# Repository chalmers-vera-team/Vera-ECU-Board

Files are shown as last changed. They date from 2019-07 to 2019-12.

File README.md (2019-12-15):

# Vera-ECU-Board
A PCB to break out connections to a MicroSquirt Engine Control Unit. Meant to be implemented for the Vera car of Chalmers Vera Team.
PCBWay sponsored the PCB and you can read about it [here!](http://chalmersverateam.se/wp-content/uploads/2019/12/PCBWAY_2019.pdf) 






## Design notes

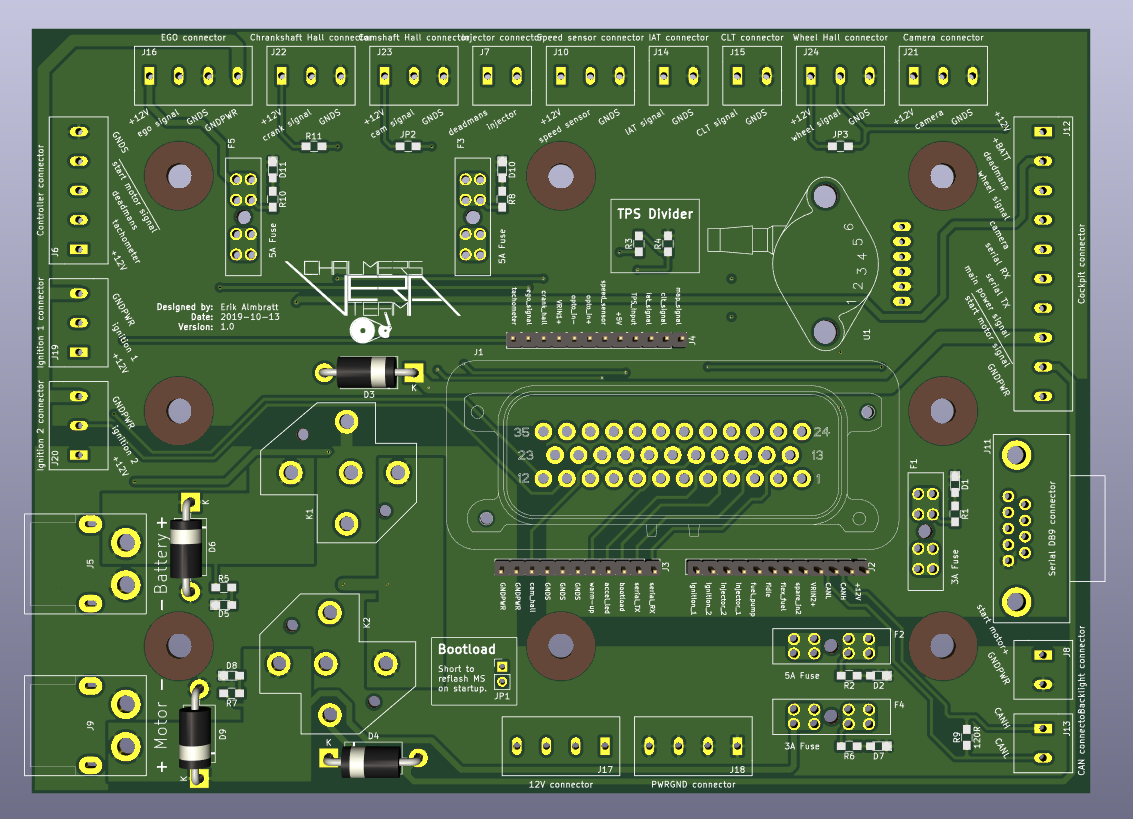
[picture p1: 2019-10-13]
ecu-board/ecu-board-model.png

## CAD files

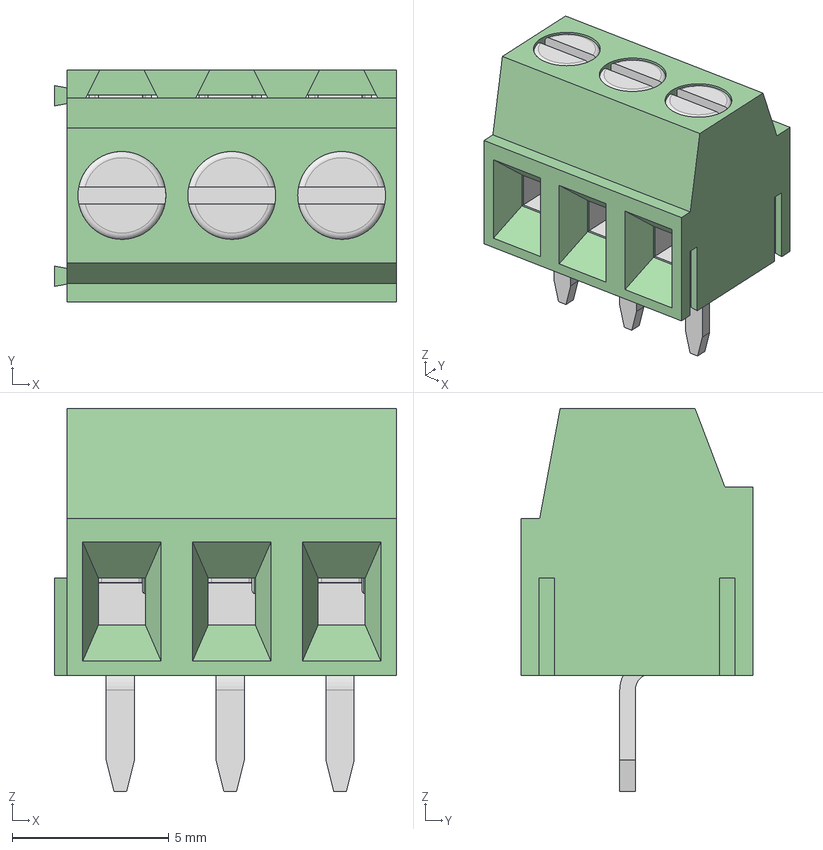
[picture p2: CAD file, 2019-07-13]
ecu-board/ecu-board-3d/wurth_2141_03x3.5mm.stp
10.9 x 7.40 x 12.2 mm
6912141100xx_CAGE x 3
6912141100xx_PIN x 3
6912141100xx_VIS x 3

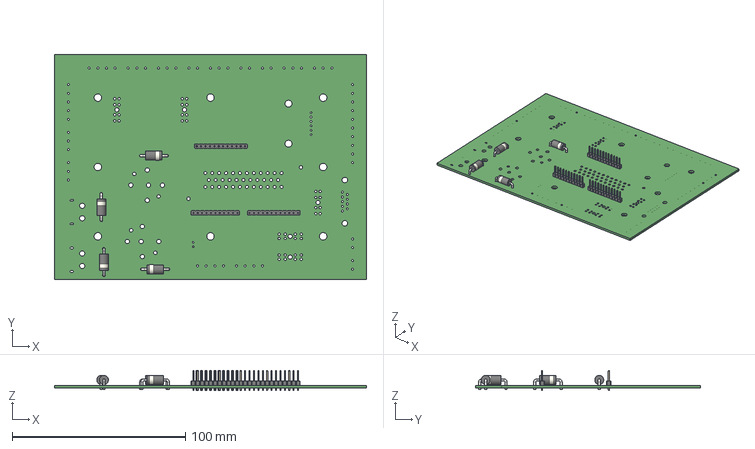
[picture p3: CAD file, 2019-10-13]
ecu-board/ecu-board.step
180.0 x 130.0 x 11.5 mm

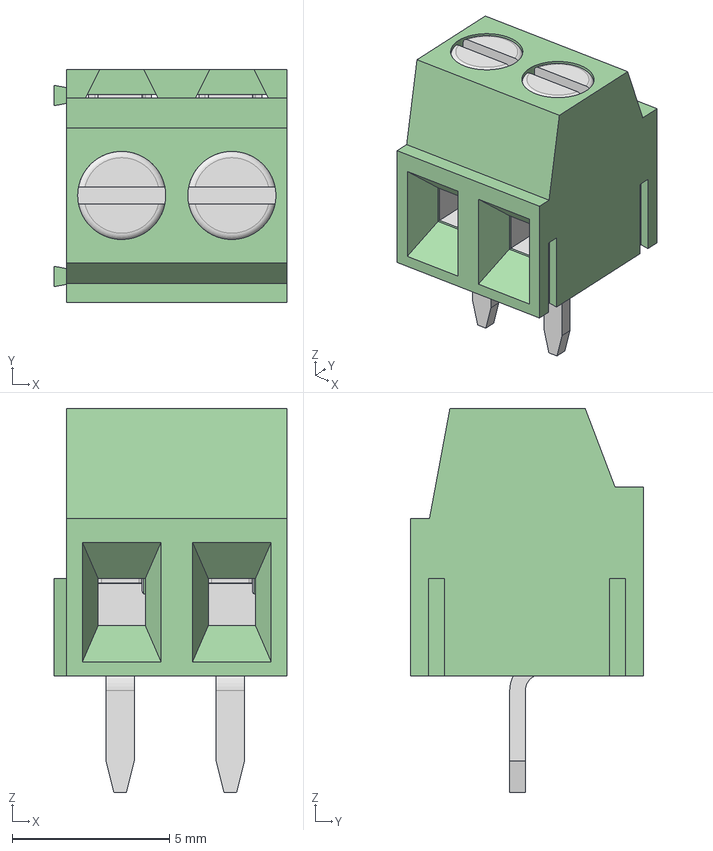
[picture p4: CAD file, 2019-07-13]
ecu-board/ecu-board-3d/wurth_2141_02x3.5mm.stp
7.40 x 7.40 x 12.2 mm
6912141100xx_CAGE x 2
6912141100xx_PIN x 2
6912141100xx_VIS x 2

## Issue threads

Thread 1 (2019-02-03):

Update crankshaft sensor model

tsuum, 2019-02-03:
Missing

tsuum, 2019-02-10:
cykn8-02cl0

Closed 2019-02-24.

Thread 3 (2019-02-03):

Make sure serial connector is correct in schematic

almbr, 2019-02-03:

Closed 2019-09-29.

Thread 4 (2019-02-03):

Verify 30A Main power fuse dimension

almbr, 2019-02-03:

tsuum, 2019-03-26:
Change to 50 A fuse. Need to use larger fuse socket.

almbr, 2019-05-16:
It's not reasonable to source a PCB-mount fuse socket of such high current rating. A in-line cable mount socket is more fit.

Closed 2019-05-16.

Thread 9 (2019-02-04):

Verify hall sensor connection

almbr, 2019-02-04:

tsuum, 2019-03-26:
Verify crankshaft sensor pull up.

almbr, 2019-05-15:
Crankshaft sensor does require pull up.

Verify that VR2IN- (cam) and VRIN1- (crank) are in use.

Closed 2019-07-04.

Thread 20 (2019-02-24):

Adapt to HMI connector board

tsuum, 2019-02-24:
- [x] Add wheel hall sensor.
- [x] Add wheel hall sensor to HMI out.
      12V/5V? And Signal?
- [x] Merge button input and HMI connector
- [x] Add Injector input button.
- [x] Add camera connector. (RCA, GNDS)
- [x] Add Serial rx, and tx

tsuum, 2019-02-24:
Need to hear with Oskar that everything is correct.

Closed 2019-03-26.

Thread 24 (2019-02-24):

Specify missing components

almbr, 2019-02-24:
- [ ] Large connectors
- [ ] New connectors
- [ ] Passives

Closed 2019-10-12.

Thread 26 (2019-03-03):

Double check Intakte air temperature circuit

almbr, 2019-03-03:
Seems like there might be a pull up in the wiring or something.

almbr, 2019-07-04:
http://www.msextra.com/doc/pdf/html/MS2V30_Hardware-3.4.pdf/MS2V30_Hardware-3.4.html

Closed 2019-07-04.

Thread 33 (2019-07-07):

Create terminal block footprint

almbr, 2019-07-07:

almbr, 2019-07-07:
**Terminals:**
https://www.phoenixcontact.com/gb/products/1791826
https://se.rs-online.com/web/p/terminal-block-accessories/1017015/?sra=pmpn

**End terminals:**
https://www.phoenixcontact.com/gb/products/1791868
https://se.rs-online.com/web/p/pcb-terminal-blocks/1017037/?sra=pmpn

Closed 2019-07-13.

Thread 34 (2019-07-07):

Create power connector footprint

almbr, 2019-07-07:

almbr, 2019-07-07:
https://se.rs-online.com/web/p/compact-power-connectors/1805375/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

Closed 2019-08-06.

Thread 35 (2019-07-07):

Implement reverse polarity protection

almbr, 2019-07-07:

almbr, 2019-07-08:
https://se.rs-online.com/web/p/mosfets/9064343/

Closed 2019-07-08.

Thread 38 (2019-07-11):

Verify reverse polarity protection circuit

almbr, 2019-07-11:

almbr, 2019-07-13:
Tested. Works well.

Closed 2019-07-13.

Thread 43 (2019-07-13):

Choose relays

almbr, 2019-07-13:
Maybe good source? https://www.12voltplanet.co.uk/relay-guide.html

almbr, 2019-07-13:
Make sure to be compliant with DIN 72552. Orient coil poles correctly to allow for integrated diode. Use ISO mini relays.

almbr, 2019-08-16:
Make relay symbol

Closed 2019-08-17.

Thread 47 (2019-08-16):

Correct Ampseal footprint name.

almbr, 2019-08-16:

almbr, 2019-08-17:
Not related to project. Take care of later.

Closed 2019-08-17.

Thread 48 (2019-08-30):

Redesign mosfet footprint

almbr, 2019-08-30:
For temp. Via in pad. Larger coolant pad.

Maybe heatsink?

Closed 2019-09-29.

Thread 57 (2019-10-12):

Double check no relay power traces are broken

almbr, 2019-10-12:

Closed 2019-10-12.

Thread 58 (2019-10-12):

Order

almbr, 2019-10-12:
- [x] Fuse holders
- [ ] Cable
- [x] Terminal blocks
- [x] Small cable ferrules
- [x] PCB spacers

Closed 2019-10-23.

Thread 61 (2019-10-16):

Larger clearance on mounting holes

almbr, 2019-10-16:
The tolerance between the solder mask and copper clearance is rather small. If the solder mask is missaligned there is a risk of a short circuit between the 12V and GND copper pours.

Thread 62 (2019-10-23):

Shorten Connector symbol values

almbr, 2019-10-23:
Footprint values are rewritten on update netlist. Therefore symbol values needs to be shortened. I.e. "EGO Connector" to "EGO".

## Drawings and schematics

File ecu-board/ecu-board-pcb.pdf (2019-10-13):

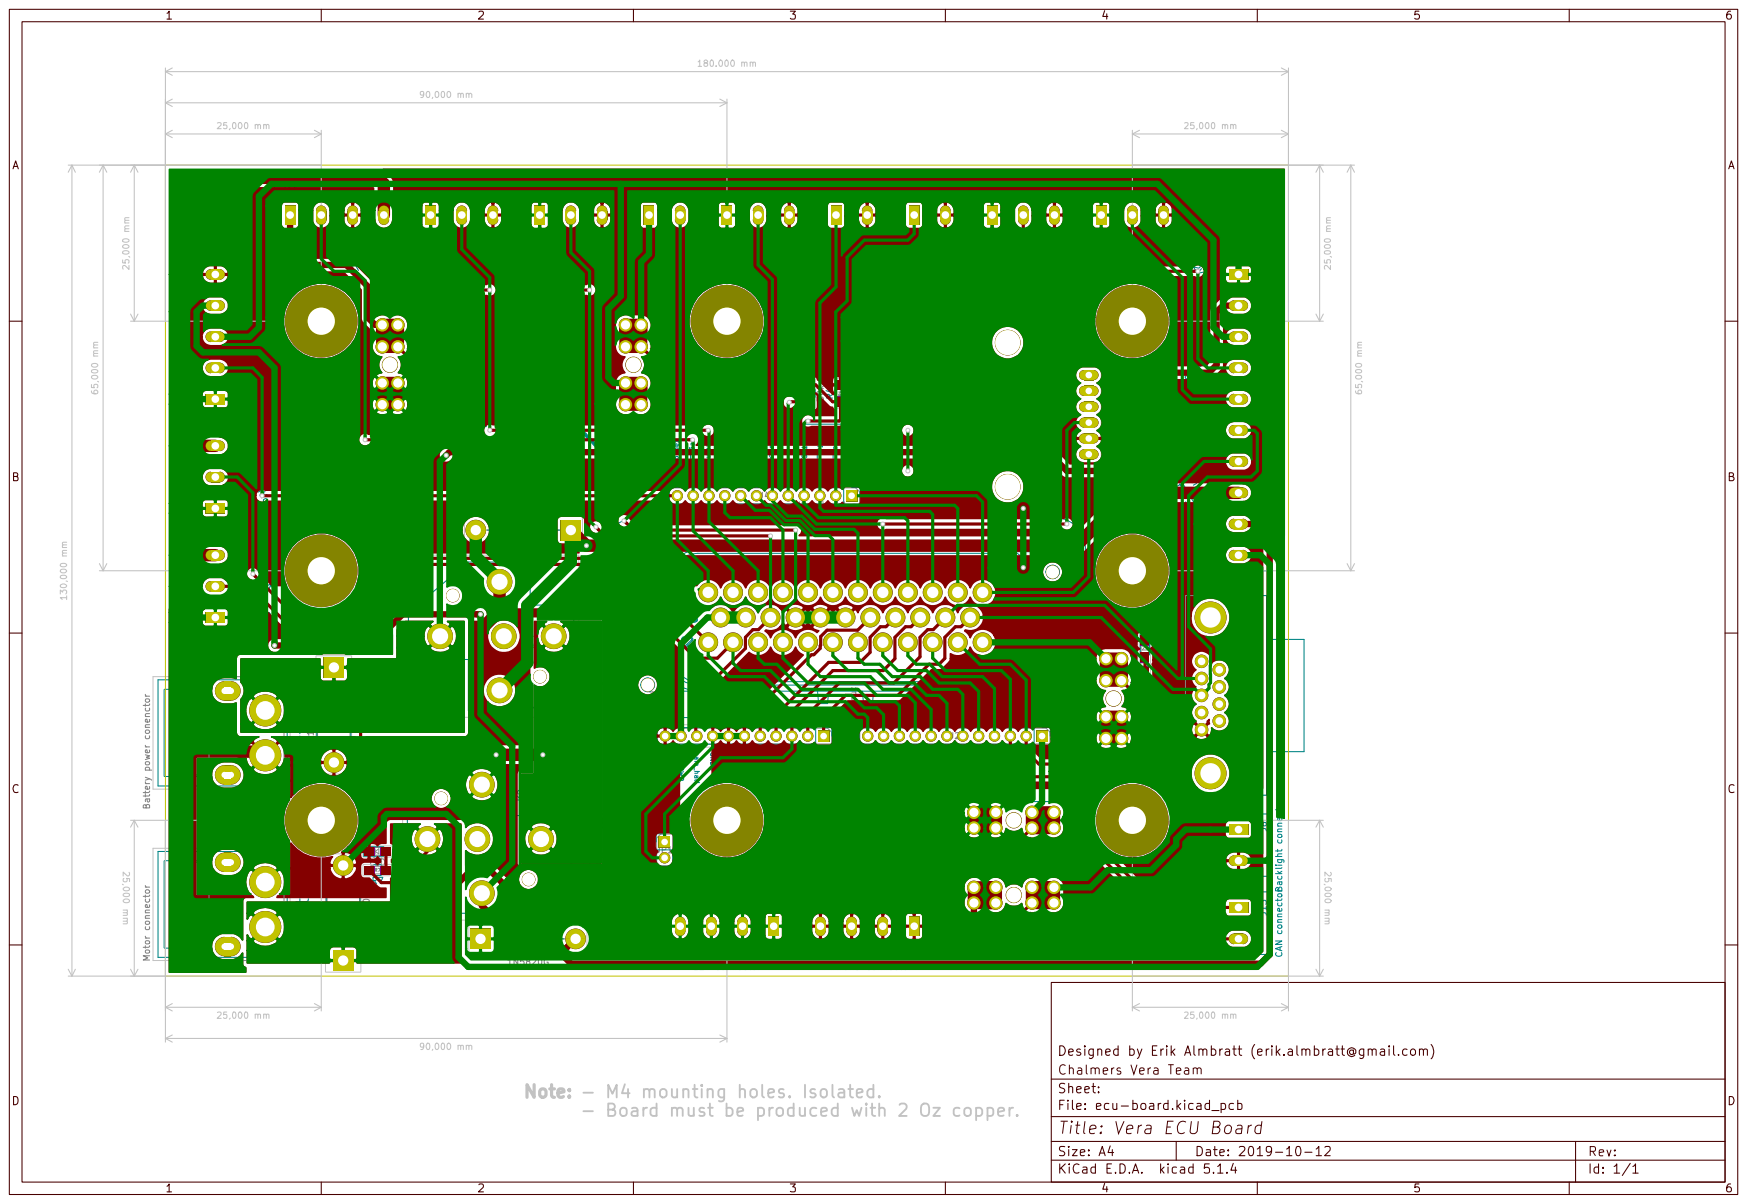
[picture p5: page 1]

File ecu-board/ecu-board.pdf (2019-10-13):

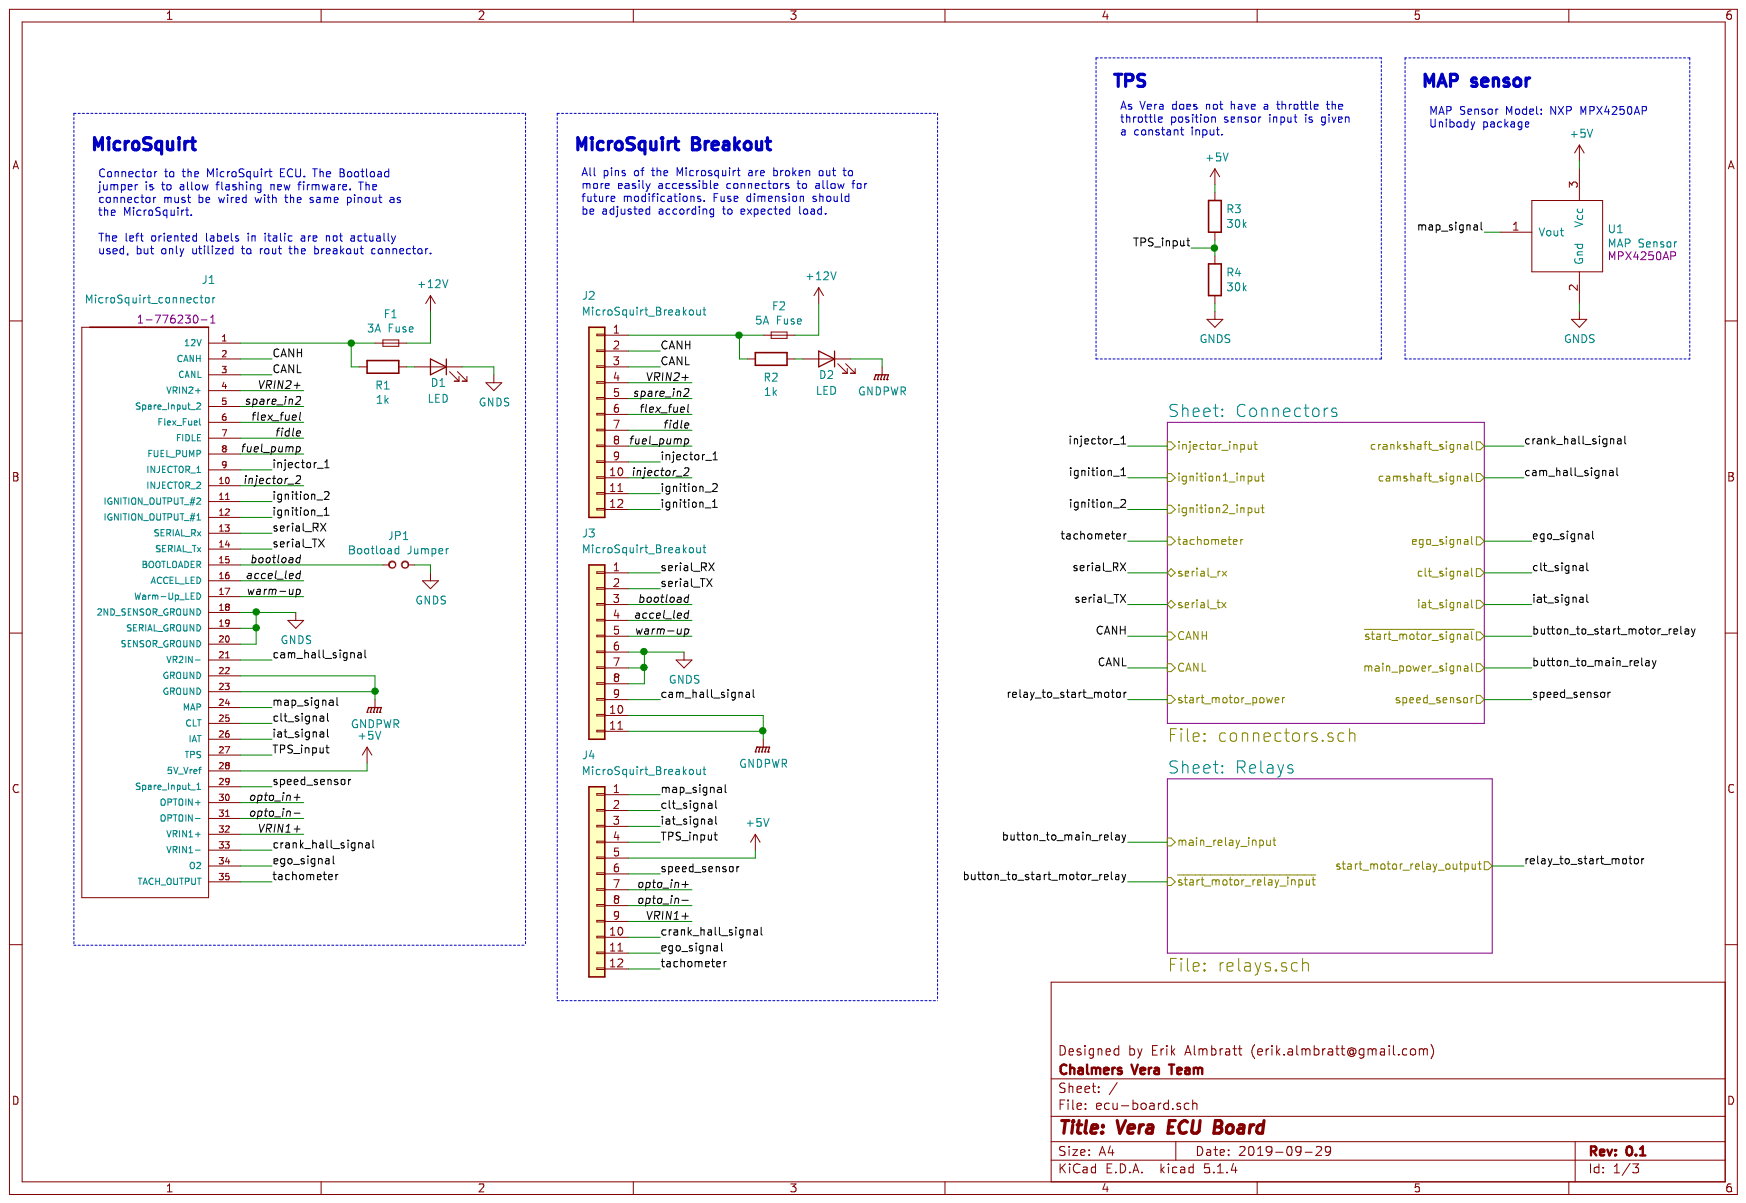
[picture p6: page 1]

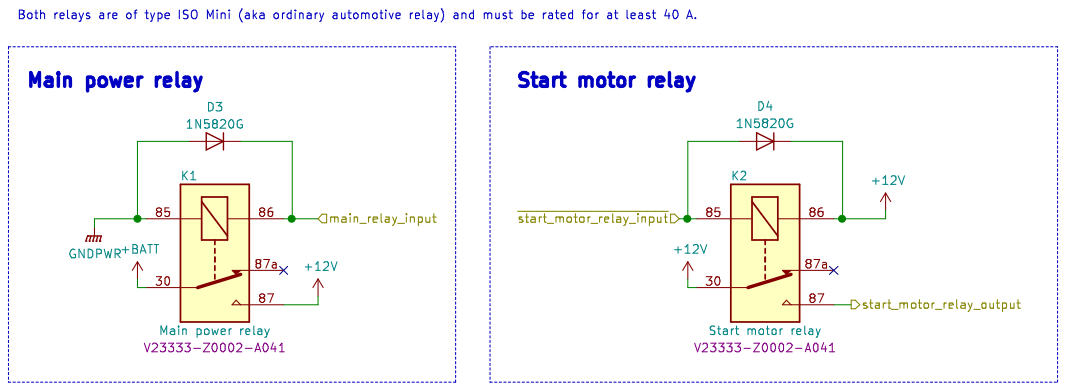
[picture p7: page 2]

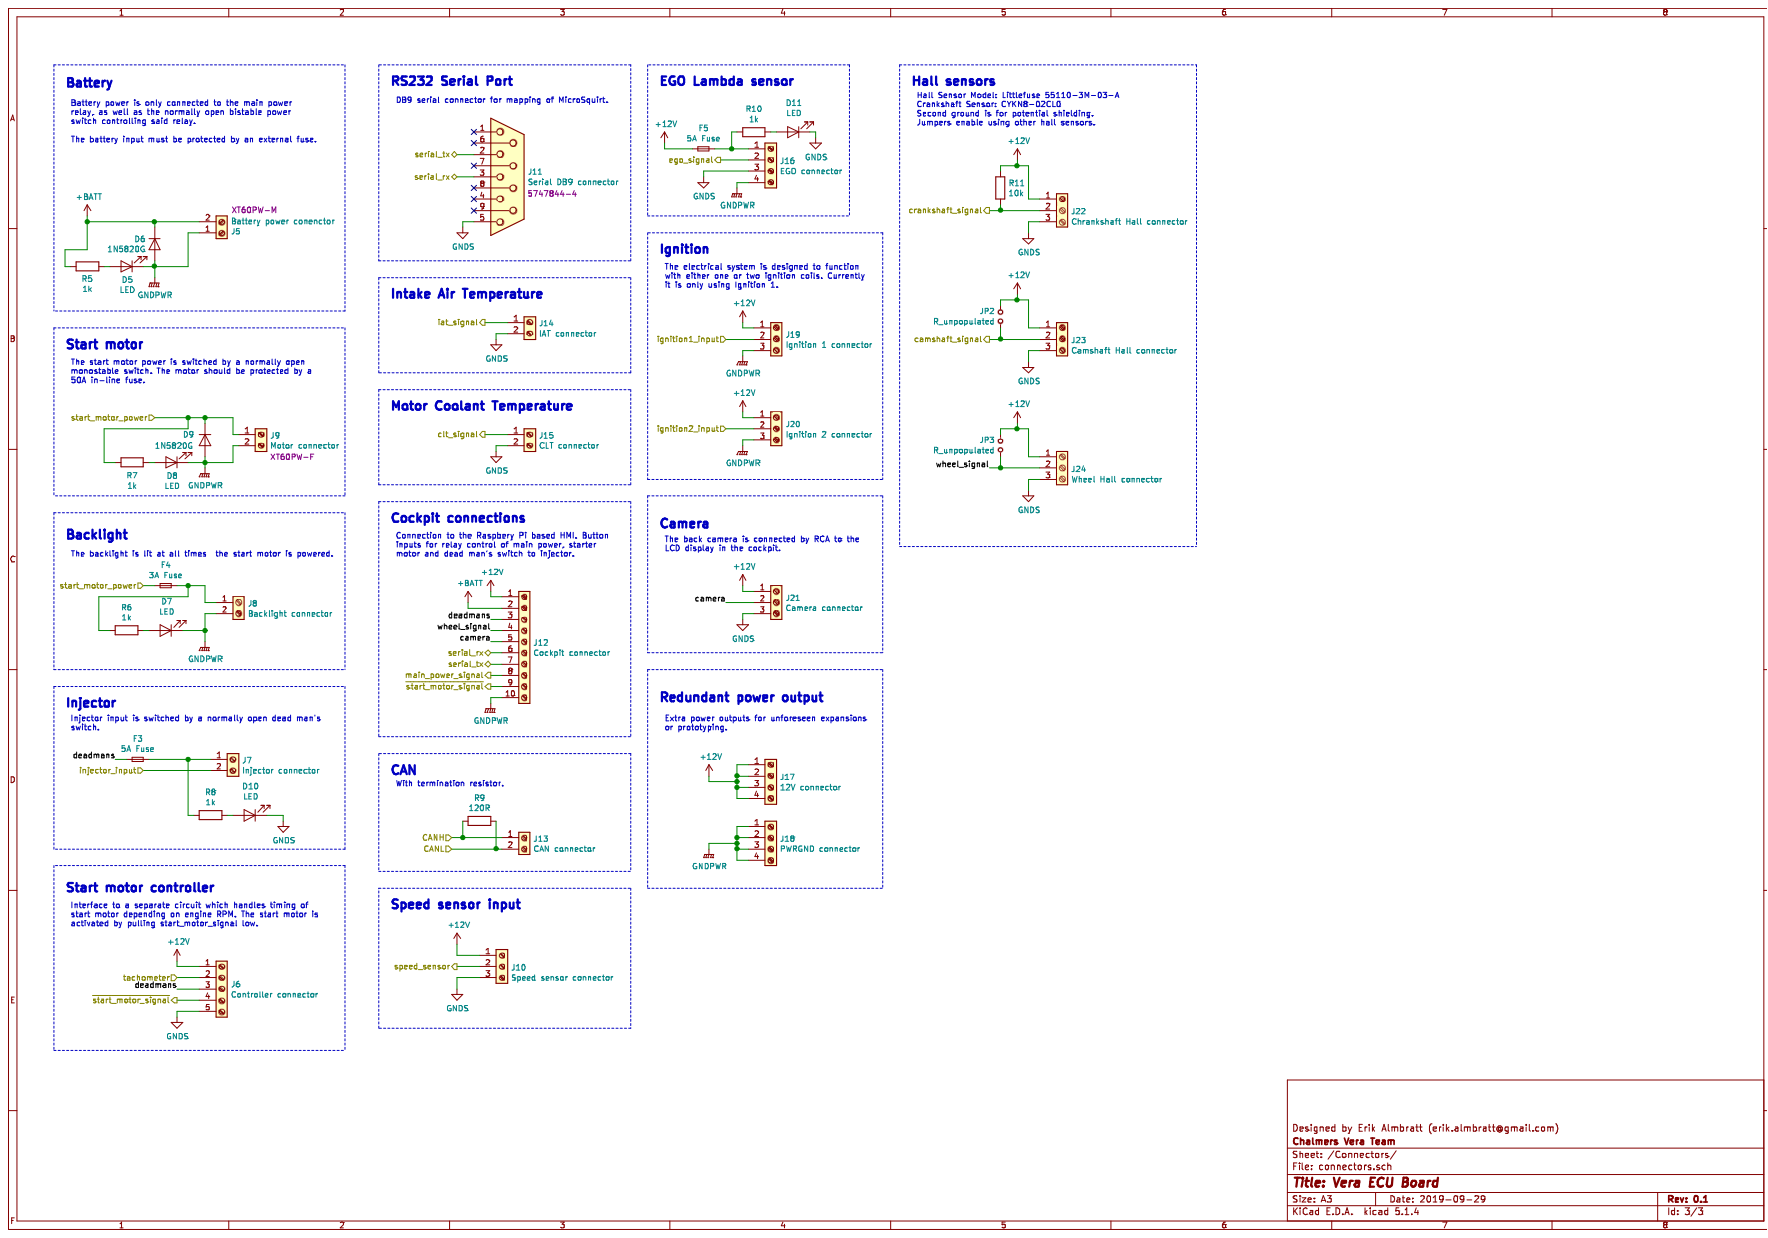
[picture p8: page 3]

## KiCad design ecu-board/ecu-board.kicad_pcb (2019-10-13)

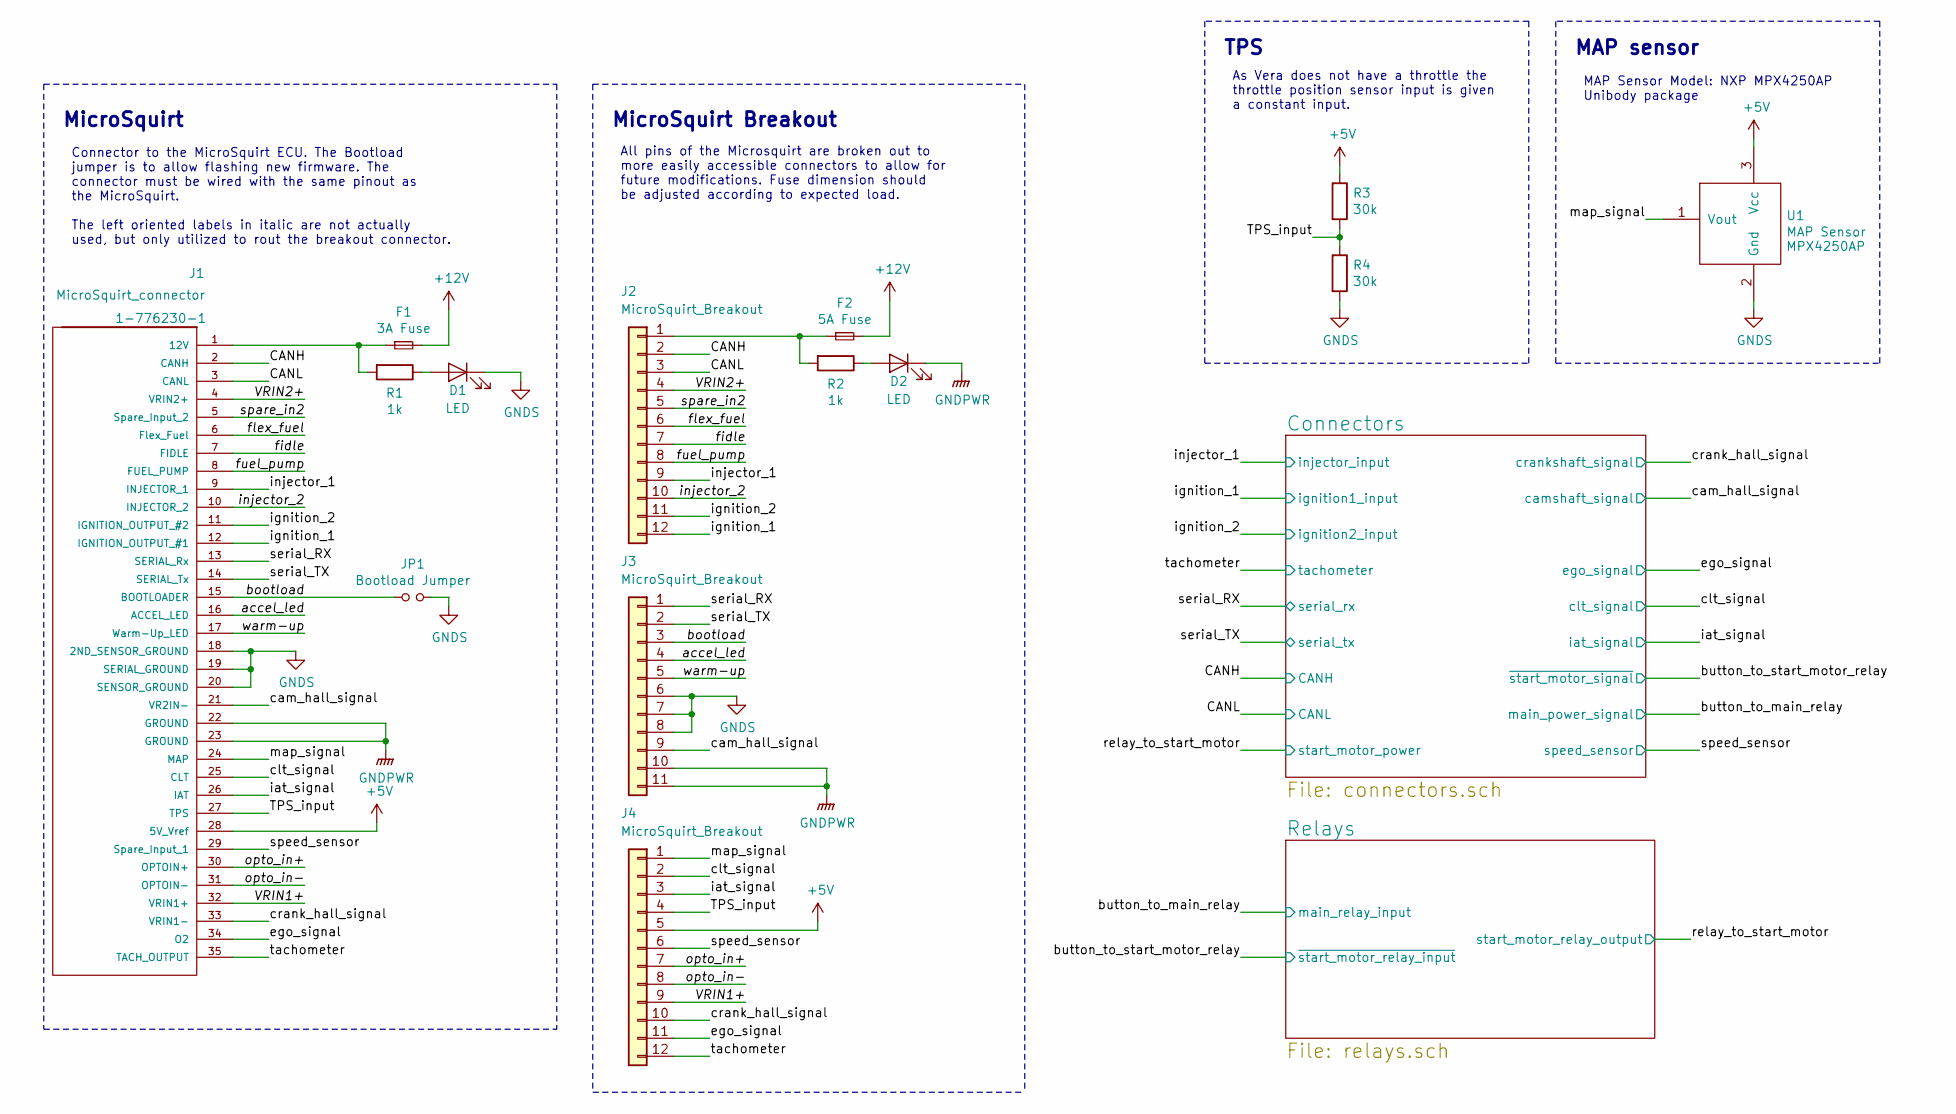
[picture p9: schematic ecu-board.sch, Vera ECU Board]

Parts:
D1, D2: LED; LED_0805_HandSoldering; Part no. 0805
F1: 3A Fuse; Fuseholder_ATO_Blade_Littelfuse_Pudenz_4_Pin; Part no. 178.4265.0002
F2: 5A Fuse; Fuseholder_ATO_Blade_Littelfuse_Pudenz_4_Pin; Part no. 178.4265.0002
J1: MicroSquirt_connector; TE_1-776230-1_35POS_P4.0mm_Vertical; Part no. 1-776230-1
J2, J4: MicroSquirt_Breakout; PinHeader_1x12_P2.54mm_Vertical; Part no. 2.54mm Pin Header
J3: MicroSquirt_Breakout; PinHeader_1x11_P2.54mm_Vertical; Part no. 2.54mm Pin Header
JP1: Bootload Jumper; Pin_Header_Straight_1x02_Pitch2.54mm; Part no. 2.54mm Pin Header
R1, R2: 1k; R_0805_HandSoldering; Part no. 0805
R3, R4: 30k; R_0805_HandSoldering; Part no. 0805
U1: MAP Sensor; SOT1852-1; Part no. MPX4250AP

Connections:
+5V: J1.28 (5V_Vref), J4.5, R3.1, U1.3 (Vcc)
+12V: F1.2, F2.2; also elsewhere on the board
/CANH: J1.2 (CANH), J2.2; also elsewhere on the board
/CANL: J1.3 (CANL), J2.3; also elsewhere on the board
/TPS_input: J1.27 (TPS), J4.4, R3.2, R4.1
/VRIN1+: J1.32 (VRIN1+), J4.9
/VRIN2+: J1.4 (VRIN2+), J2.4
/accel_led: J1.16 (ACCEL_LED), J3.4
/bootload: J1.15 (BOOTLOADER), J3.3, JP1.1
/cam_hall_signal: J1.21 (VR2IN-), J3.9; also elsewhere on the board
/clt_signal: J1.25 (CLT), J4.2; also elsewhere on the board
/crank_hall_signal: J1.33 (VRIN1-), J4.10; also elsewhere on the board
/ego_signal: J1.34 (O2), J4.11; also elsewhere on the board
/fidle: J1.7 (FIDLE), J2.7
/flex_fuel: J1.6 (Flex_Fuel), J2.6
/fuel_pump: J1.8 (FUEL_PUMP), J2.8
/iat_signal: J1.26 (IAT), J4.3; also elsewhere on the board
/ignition_1: J1.12 (IGNITION_OUTPUT_#1), J2.12; also elsewhere on the board
/ignition_2: J1.11 (IGNITION_OUTPUT_#2), J2.11; also elsewhere on the board
/injector_1: J1.9 (INJECTOR_1), J2.9; also elsewhere on the board
/injector_2: J1.10 (INJECTOR_2), J2.10
/map_signal: J1.24 (MAP), J4.1, U1.1 (Vout)
/opto_in+: J1.30 (OPTOIN+), J4.7
/opto_in-: J1.31 (OPTOIN-), J4.8
/serial_RX: J1.13 (SERIAL_Rx), J3.1; also elsewhere on the board
/serial_TX: J1.14 (SERIAL_Tx), J3.2; also elsewhere on the board
/spare_in2: J1.5 (Spare_Input_2), J2.5
/speed_sensor: J1.29 (Spare_Input_1), J4.6; also elsewhere on the board
/tachometer: J1.35 (TACH_OUTPUT), J4.12; also elsewhere on the board
/warm-up: J1.17 (Warm-Up_LED), J3.5
GNDPWR: D2.1 (K), J1.22 (GROUND), J1.23 (GROUND), J3.10, J3.11; also elsewhere on the board
GNDS: D1.1 (K), J1.18 (2ND_SENSOR_GROUND), J1.19 (SERIAL_GROUND), J1.20 (SENSOR_GROUND), J3.6, J3.7, J3.8, JP1.2, R4.2, U1.2 (Gnd); also elsewhere on the board
unnamed: D1.2 (A), R1.1
unnamed: D2.2 (A), R2.1
unnamed: F1.1, J1.1 (12V), R1.2
unnamed: F2.1, J2.1, R2.2

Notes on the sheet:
MicroSquirt
Connector to the MicroSquirt ECU. The Bootload jumper is to allow flashing new firmware. The connector must be wired with the same pinout as the MicroSquirt. The left oriented labels in italic are not actually used, but only utilized to rout the breakout connector.
MAP sensor
MAP Sensor Model: NXP MPX4250AP Unibody package
TPS
As Vera does not have a throttle the throttle position sensor input is given a constant input.
MicroSquirt Breakout
All pins of the Microsquirt are broken out to more easily accessible connectors to allow for future modifications. Fuse dimension should be adjusted according to expected load.

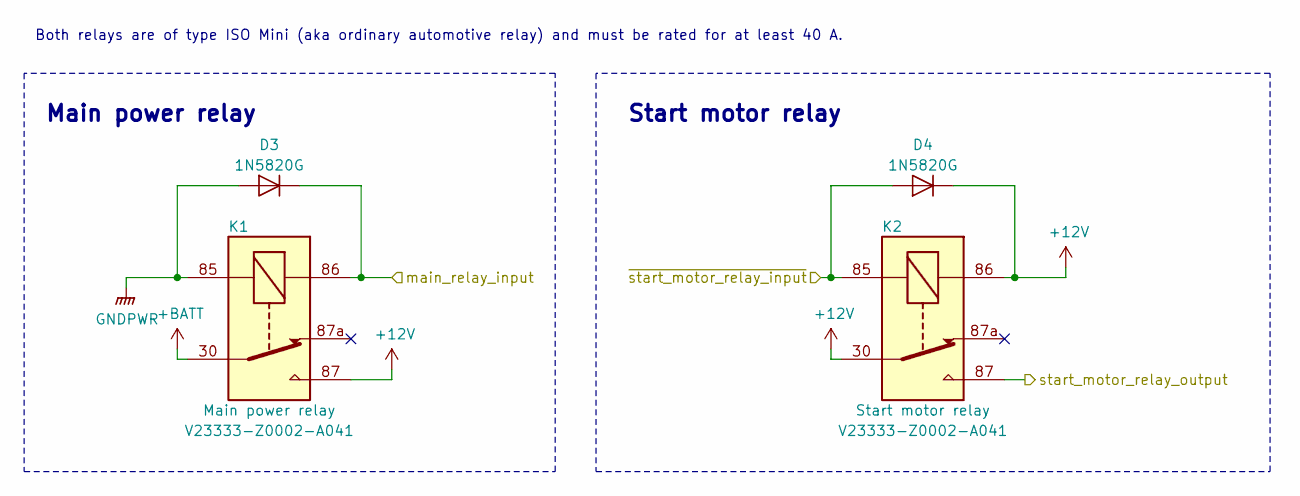
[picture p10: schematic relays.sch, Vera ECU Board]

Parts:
D3, D4: 1N5820G; D_DO-201AD_P15.24mm_Horizontal; Part no. 1N5820G
K1: Main power relay; TE_2-1904045-4; Part no. V23333-Z0002-A041
K2: Start motor relay; TE_2-1904045-4; Part no. V23333-Z0002-A041

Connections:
+12V: D4.1 (K), K1.87, K2.30, K2.86; also elsewhere on the board
+BATT: K1.30; also elsewhere on the board
/button_to_main_relay: D3.1 (K), K1.86; also elsewhere on the board
/button_to_start_motor_relay: D4.2 (A), K2.85; also elsewhere on the board
/relay_to_start_motor: K2.87; also elsewhere on the board
GNDPWR: D3.2 (A), K1.85; also elsewhere on the board

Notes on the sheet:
Main power relay
Start motor relay
Both relays are of type ISO Mini (aka ordinary automotive relay) and must be rated for at least 40 A.

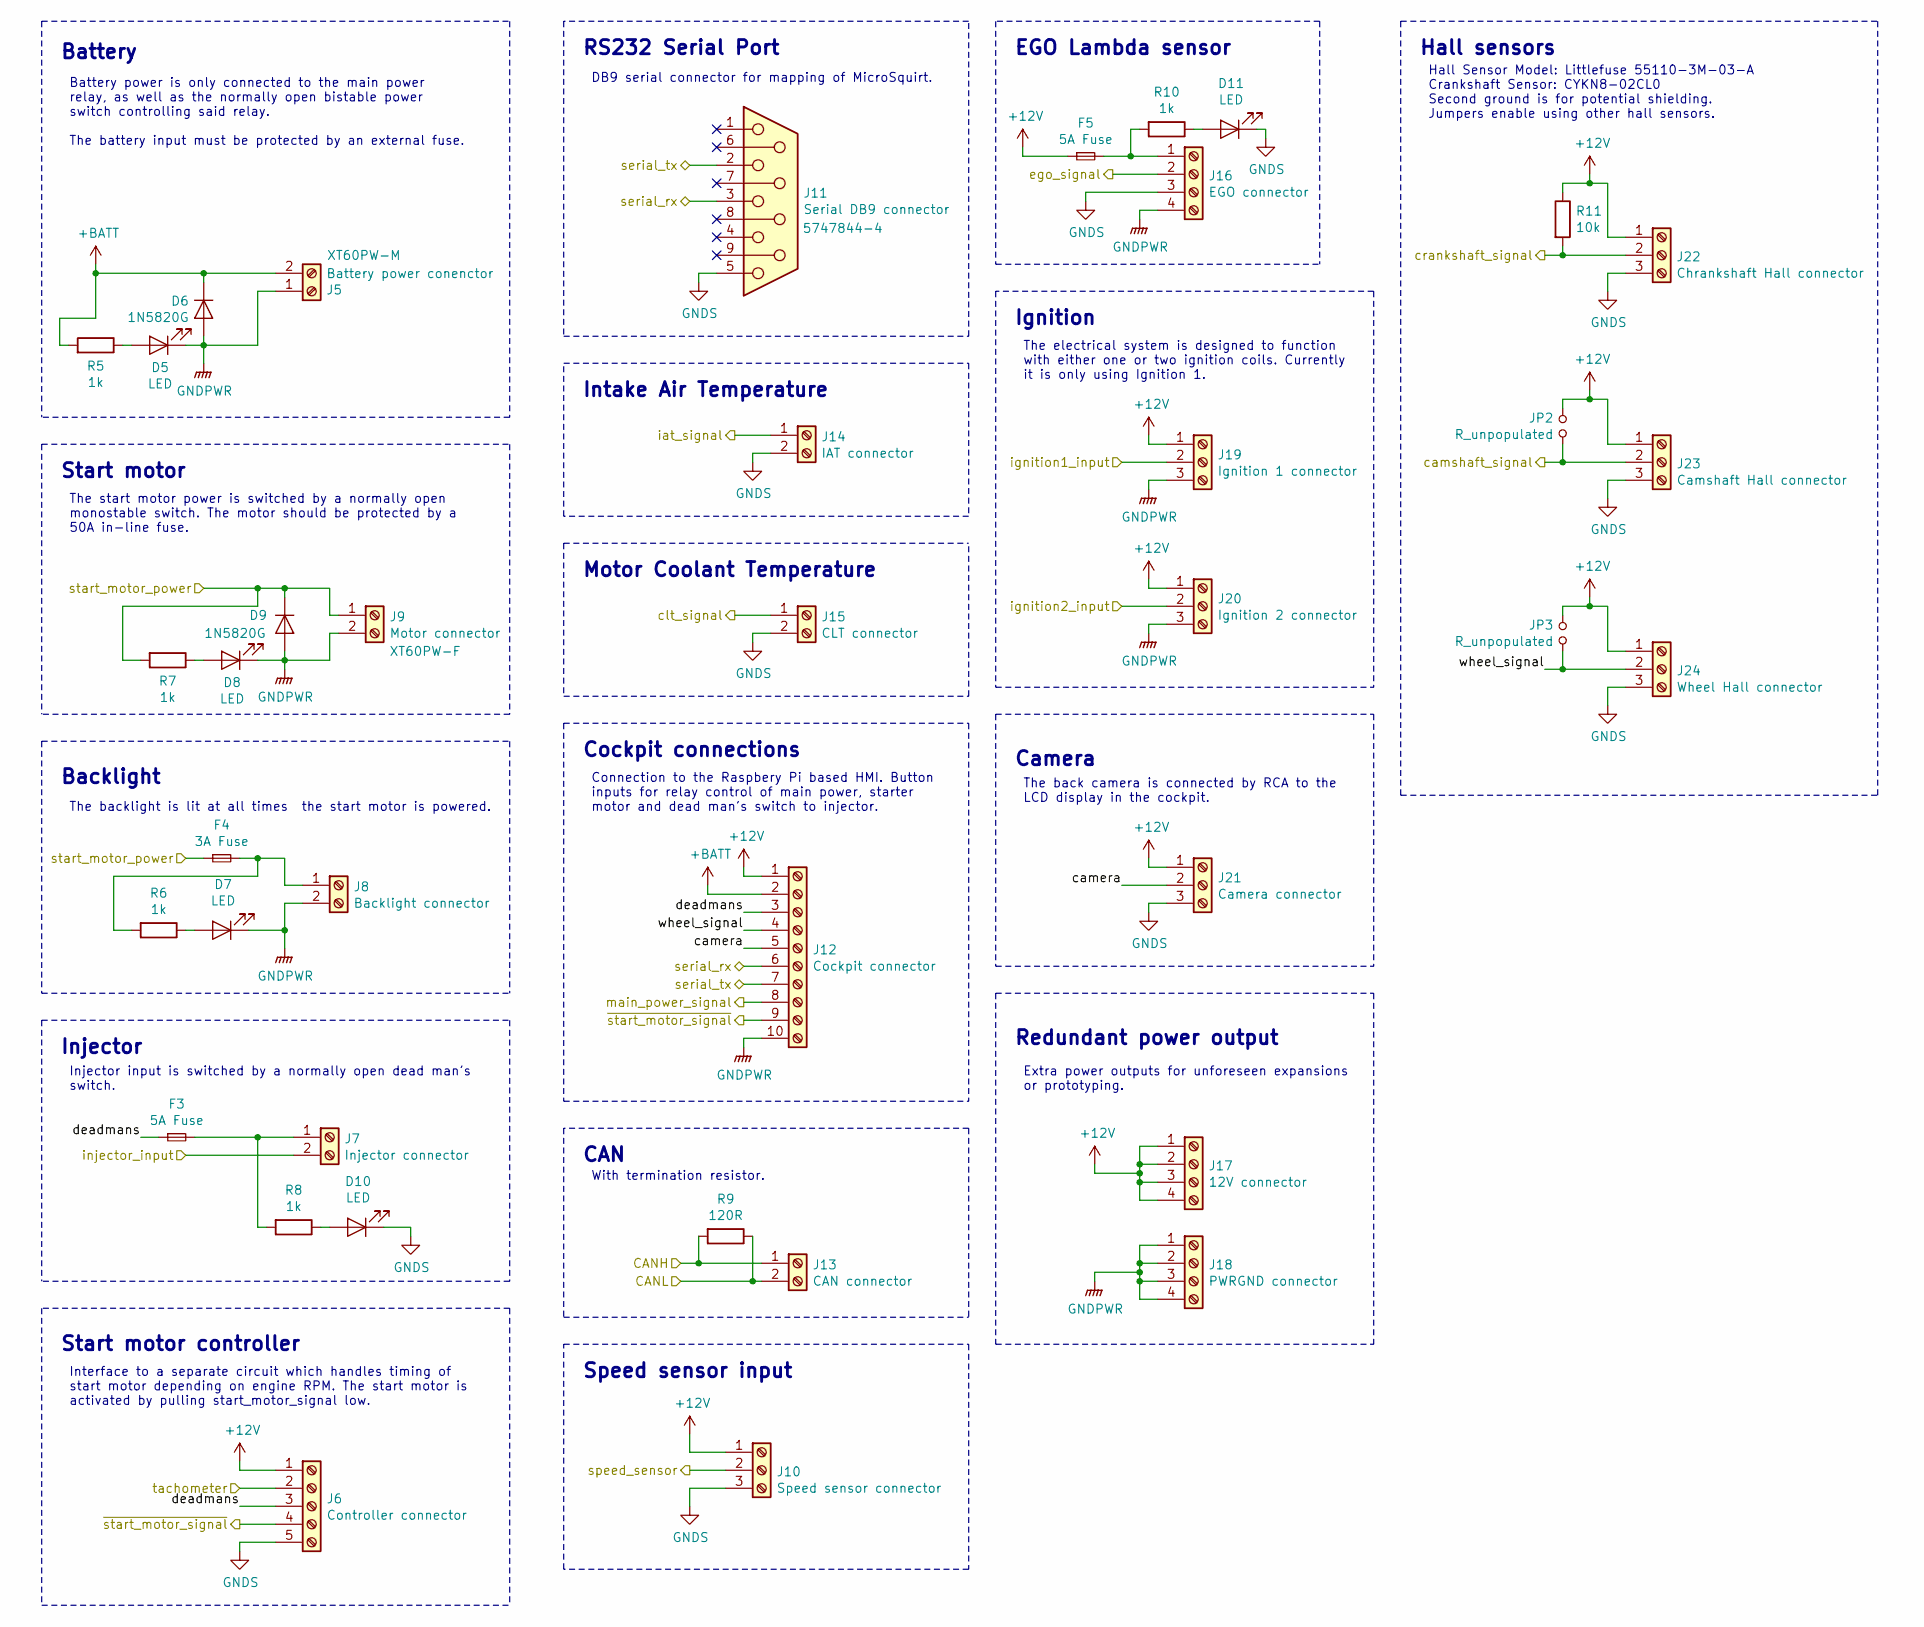
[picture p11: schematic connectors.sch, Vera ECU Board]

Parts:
D5, D7, D8, D10, D11: LED; LED_0805_HandSoldering; Part no. 0805
D6, D9: 1N5820G; D_DO-201AD_P15.24mm_Horizontal; Part no. 1N5820G
F3, F5: 5A Fuse; Fuseholder_ATO_Blade_Littelfuse_Pudenz_4_Pin; Part no. 178.4265.0002
F4: 3A Fuse; Fuseholder_ATO_Blade_Littelfuse_Pudenz_4_Pin; Part no. 178.4265.0002
J5: Battery power conenctor; AMASS_XT60PW; Part no. XT60PW-M
J6: Controller connector; Terminal_Block_5x5.00mm; Part no. 897-0812
J7: Injector connector; Terminal_Block_2x5.00mm; Part no. 897-0803
J8: Backlight connector; Terminal_Block_2x5.00mm; Part no. 897-0803
J9: Motor connector; AMASS_XT60PW; Part no. XT60PW-F
J10: Speed sensor connector; Terminal_Block_3x5.00mm; Part no. 897-0812
J11: Serial DB9 connector; TE_5747844-4; Part no. 5747844-4
J12: Cockpit connector; Terminal_Block_10x5.00mm; Part no. 897-0803
J13: CAN connector; Terminal_Block_2x5.00mm; Part no. 897-0803
J14: IAT connector; Terminal_Block_2x5.00mm; Part no. 897-0803
J15: CLT connector; Terminal_Block_2x5.00mm; Part no. 897-0803
J16: EGO connector; Terminal_Block_4x5.00mm; Part no. 897-0803
J17: 12V connector; Terminal_Block_4x5.00mm; Part no. 897-0803
J18: PWRGND connector; Terminal_Block_4x5.00mm; Part no. 897-0803
J19: Ignition 1 connector; Terminal_Block_3x5.00mm; Part no. 897-0812
J20: Ignition 2 connector; Terminal_Block_3x5.00mm; Part no. 897-0812
J21: Camera connector; Terminal_Block_3x5.00mm; Part no. 897-0812
J22: Chrankshaft Hall connector; Terminal_Block_3x5.00mm; Part no. 897-0812
J23: Camshaft Hall connector; Terminal_Block_3x5.00mm; Part no. 897-0812
J24: Wheel Hall connector; Terminal_Block_3x5.00mm; Part no. 897-0812
JP2, JP3: R_unpopulated; R_0805_HandSoldering; Part no. 0805
R5, R6, R7, R8, R10: 1k; R_0805_HandSoldering; Part no. 0805
R9: 120R; R_0805_HandSoldering; Part no. 0805
R11: 10k; R_0805_HandSoldering; Part no. 0805

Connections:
+12V: F5.1, J6.1, J10.1, J12.1, J17.1, J17.2, J17.3, J17.4, J19.1, J20.1, J21.1, J22.1, J23.1, J24.1, JP2.2, JP3.2, R11.1; also elsewhere on the board
+BATT: D6.1 (K), J5.2, J12.2, R5.2; also elsewhere on the board
/CANH: J13.1, R9.2; also elsewhere on the board
/CANL: J13.2, R9.1; also elsewhere on the board
/Connectors/camera: J12.5, J21.2
/Connectors/deadmans: F3.1, J6.3, J12.3
/Connectors/wheel_signal: J12.4, J24.2, JP3.1
/button_to_main_relay: J12.8; also elsewhere on the board
/button_to_start_motor_relay: J6.4, J12.9; also elsewhere on the board
/cam_hall_signal: J23.2, JP2.1; also elsewhere on the board
/clt_signal: J15.1; also elsewhere on the board
/crank_hall_signal: J22.2, R11.2; also elsewhere on the board
/ego_signal: J16.2; also elsewhere on the board
/iat_signal: J14.1; also elsewhere on the board
/ignition_1: J19.2; also elsewhere on the board
/ignition_2: J20.2; also elsewhere on the board
/injector_1: J7.2; also elsewhere on the board
/relay_to_start_motor: D9.1 (K), F4.1, J9.1, R7.2; also elsewhere on the board
/serial_RX: J11.3, J12.6; also elsewhere on the board
/serial_TX: J11.2, J12.7; also elsewhere on the board
/speed_sensor: J10.2; also elsewhere on the board
/tachometer: J6.2; also elsewhere on the board
GNDPWR: D5.1 (K), D6.2 (A), D7.1 (K), D8.1 (K), D9.2 (A), J5.1, J8.2, J9.2, J12.10, J16.4, J18.1, J18.2, J18.3, J18.4, J19.3, J20.3; also elsewhere on the board
GNDS: D10.1 (K), D11.1 (K), J6.5, J10.3, J11.5, J14.2, J15.2, J16.3, J21.3, J22.3, J23.3, J24.3; also elsewhere on the board
unnamed: D5.2 (A), R5.1
unnamed: D7.2 (A), R6.1
unnamed: D8.2 (A), R7.1
unnamed: D10.2 (A), R8.1
unnamed: D11.2 (A), R10.1
unnamed: F3.2, J7.1, R8.2
unnamed: F4.2, J8.1, R6.2
unnamed: F5.2, J16.1, R10.2

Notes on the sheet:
Hall Sensor Model: Littlefuse 55110-3M-03-A Crankshaft Sensor: CYKN8-02CL0 Second ground is for potential shielding. Jumpers enable using other hall sensors.
Hall sensors
EGO Lambda sensor
RS232 Serial Port
DB9 serial connector for mapping of MicroSquirt.
Injector
Injector input is switched by a normally open dead man's switch.
Motor Coolant Temperature
Intake Air Temperature
Battery
Start motor
The start motor power is switched by a normally open monostable switch. The motor should be protected by a 50A in-line fuse.
Ignition
The electrical system is designed to function with either one or two ignition coils. Currently it is only using Ignition 1.
Cockpit connections
Connection to the Raspbery Pi based HMI. Button inputs for relay control of main power, starter motor and dead man's switch to injector.
Start motor controller
Interface to a separate circuit which handles timing of start motor depending on engine RPM. The start motor is activated by pulling start_motor_signal low.
Camera
The back camera is connected by RCA to the LCD display in the cockpit.
Backlight
The backlight is lit at all times the start motor is powered.
Battery power is only connected to the main power relay, as well as the normally open bistable power switch controlling said relay. The battery input must be protected by an external fuse.
CAN
Speed sensor input
With termination resistor.
Redundant power output
Extra power outputs for unforeseen expansions or prototyping.

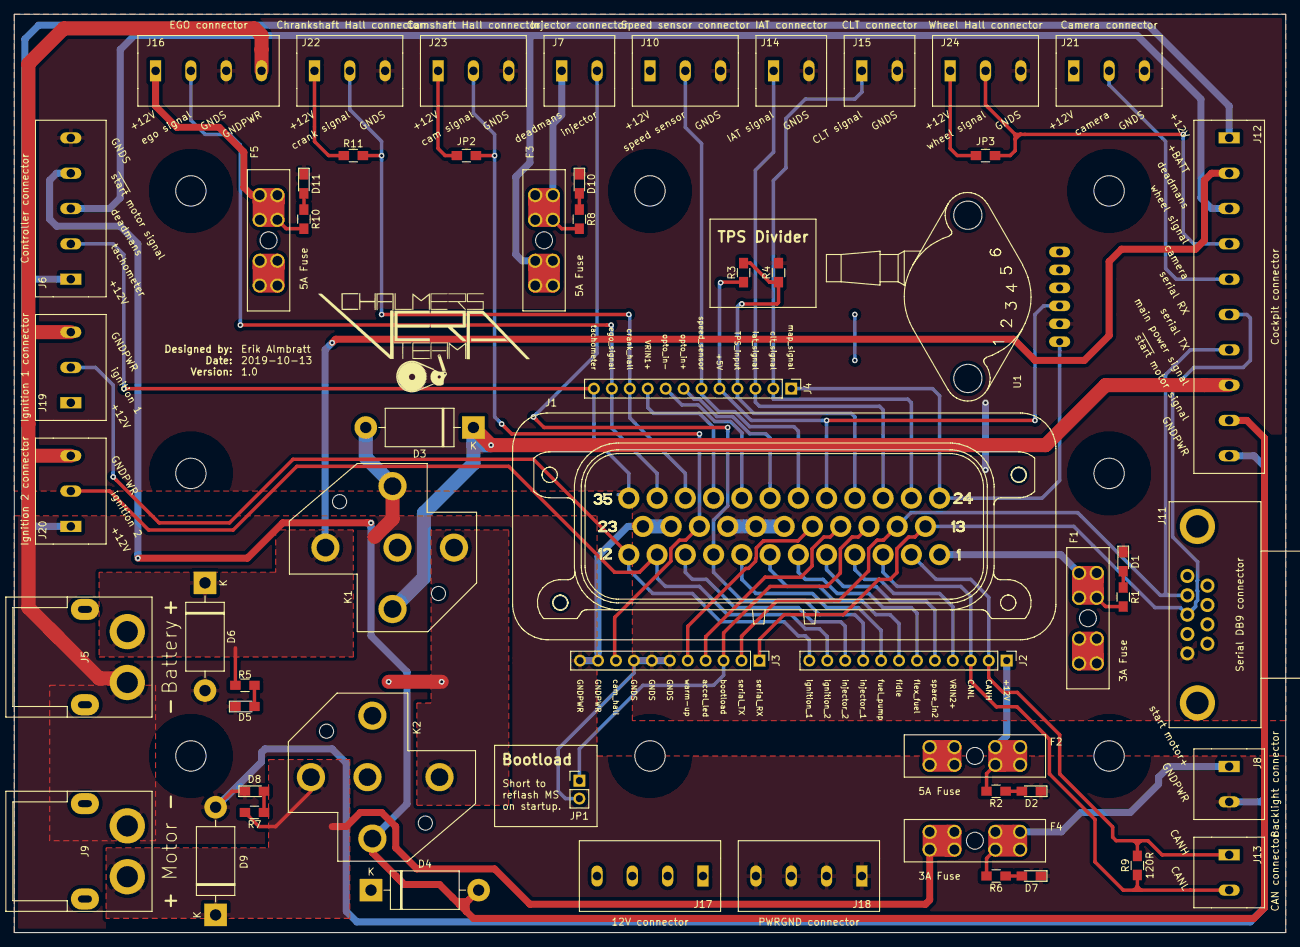
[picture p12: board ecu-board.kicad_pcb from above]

Board: 2 copper layers, 180.0 x 130.0 mm, 57 parts (0 on the bottom side), 51 nets.

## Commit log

2019-02-03 Hall and MAP sensor connectors created.
    [connectors.sch, ecu-board.kicad_pcb, ecu-board.sch]
2019-02-04 Schematic completed. Now to confirm details and proof-read.
    [connectors.sch, ecu-board.sch, relays.sch]
2019-02-24 Add Power Ground to lambda connector
    [connectors.sch]
2019-02-24 Remove relay pull downs.
    [connectors.sch]
2019-02-24 Update crankshaft sensor model.
    [connectors.sch]
2019-02-24 Mount MAP sensor to PCB. Reverse injector input.
    [connectors.sch, ecu-board.sch]
2019-02-24 Cockpit connector expanded and merged with button connector. Injector connected to dead man's switch.
    [connectors.sch, ecu-board.sch]
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2019-03-26 Change TPS. Resolved #27.
    [ecu-board.sch]
2019-03-26 Add pull up to Crankshaft hall. Resolves #16.
    [connectors.sch]
2019-03-26 Add pull up placeholders to hall sensors. Resolves #18
    [connectors.sch]
2019-03-26 Moved tachometer output and start motor controll to separate circuit. Resolves #20 and resolves #25.
    [connectors.sch]
2019-03-26 Added indicator LEDs to fuses. Resolves #15.
    [connectors.sch, ecu-board.sch]
2019-03-29 Clean up schematic graphics.
    [connectors.sch]
2019-05-15 Specified diodes.
    [connectors.sch, ecu-board.sch, relays.sch]
2019-05-15 Change start motor relay connection. To comply with the external start motor module. Solves #28.
    [connectors.sch, relays.sch]
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2019-05-16 Remove main fuse. To be replaced by inline. See #4.
    [connectors.sch]
2019-05-16 Add camera connector. #21.
    [connectors.sch]
2019-05-16 Add backlight connector. Resolves #21.
    [connectors.sch]
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2019-07-04 Change starter motor fuse to 40A. Closes #30.
    [connectors.sch]
2019-07-04 Remove unecessary pull-down.
    [connectors.sch]
2019-07-04 Change hal connectors from 4 to 3 pin.
    [connectors.sch]
2019-07-04 Add backlight fuse. Closes #31.
    [connectors.sch]
2019-07-06 Update SVGs
    [ecu-board.sch]
2019-07-06 Add info about start motor.
    [connectors.sch]
2019-07-07 Add MicroSquirt Breakout. Closes #10.
    [connectors.sch, ecu-board.sch, relays.sch]
2019-07-07 Add footprint information.
    [connectors.sch, ecu-board.sch]
2019-07-08 Add reverse polarity protection. Closes #35.
    [connectors.sch, ecu-board.sch, relays.sch]
2019-07-08 Mirror MOSFET orientationgit status
    [connectors.sch, ecu-board.sch]
2019-07-13 Add Wurth terminal block footprints.
    [wurth_2141_02x3.5mm.stp, wurth_2141_03x3.5mm.stp]
2019-07-13 Assign 2- and 3-pin terminal footprints.
    [connectors.sch, ecu-board.sch]
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2019-07-14 Assign block terminal footprints.
    [connectors.sch, ecu-board.sch]
2019-07-14 Add component part no.
    [connectors.sch, ecu-board.sch]
2019-07-14 Display power connector part no.
    [connectors.sch]
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2019-08-06 Assign XT60PW footprints to symbols.
    [connectors.sch]
2019-08-06 Update mosfet data sheet.
    [connectors.sch]
2019-08-06 Add relay article information.
    [relays.sch]
2019-08-06 Remove legacy Farnell article no.
    [connectors.sch]
2019-08-06 Update DB9 article information.
    [connectors.sch]
2019-08-06 Remove legacy datasheet.
    [connectors.sch]
2019-08-06 Add DB9 footprint.
    [connectors.sch]
2019-08-06 Remove start motor fuse due to too high current.
    [connectors.sch]
2019-08-06 Change diodes.
    [connectors.sch, relays.sch]
2019-08-06 Update LEDs.
    [connectors.sch, ecu-board.sch]
2019-08-06 Update MAP sensor value.
    [ecu-board.sch]
2019-08-06 Update jumper info.
    [ecu-board.sch]
2019-08-06 Update fuse holder info.
    [connectors.sch, ecu-board.sch]
2019-08-06 Assign resistor footprints.
    [connectors.sch, ecu-board.sch]
2019-08-06 Assign diode footprints.
    [connectors.sch, relays.sch]
2019-08-06 Assign jumper footprint.
    [ecu-board.sch]
2019-08-12 Initial placement on components.
    [ecu-board.kicad_pcb]
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2019-08-17 Update dsub connector in pcb. Closes #42.
    [ecu-board.kicad_pcb]
2019-08-17 Ignore lib cache files.
    [ecu-board.kicad_pcb, relays.sch]
2019-08-17 Add part names to relay symbols.
    [relays.sch]
2019-08-17 Add part values to connector symbols.
    [connectors.sch, ecu-board.sch]
2019-08-17 Reassign footprints to 0805.
    [connectors.sch, ecu-board.sch]
2019-08-17 Change from 3.50mm to 5.00mm terminal blocks.
    [connectors.sch, ecu-board.kicad_pcb]
2019-08-29 Change fuse part no.
    [connectors.sch, ecu-board.sch]
2019-08-29 Add fuse holder footprint.
    [connectors.sch, ecu-board.sch]
2019-08-29 Import fuse holders to pcb.
    [ecu-board.kicad_pcb]
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2019-08-30 Rearrange some components on pcb.
    [ecu-board.kicad_pcb]
2019-09-29 Change reverse polarity protection to diode.
    [connectors.sch]
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2019-09-29 Add speed sensor connector.
    [connectors.sch, ecu-board.sch]
2019-09-29 Add CAN termination resitor.
    [connectors.sch]
2019-09-29 Start power circuit routing.
    [connectors.sch, ecu-board.kicad_pcb, ecu-board.sch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]
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2019-10-04 Create isolated M4 footprint.
    [ecu-board.kicad_pcb]
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2019-10-12 Change cockpit ground from SGND to PWRGND.
    [connectors.sch, ecu-board.kicad_pcb]
2019-10-12 Add redundant 12V and PWRGND connectors. Closes #52. Also add PWRGND copper pour.
    [connectors.sch, ecu-board.kicad_pcb, relays.sch]
2019-10-12 Correct BOM to present components.
    [connectors.sch, ecu-board.sch, relays.sch]
2019-10-12 Split MicroSquirt breakout connector into three separate connectors. Old connector was impossible to route.
    [connectors.sch, ecu-board.kicad_pcb, ecu-board.sch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]
2019-10-12 Change block terminal article.
    [connectors.sch, ecu-board.kicad_pcb]
2019-10-12 Add connector pinout to silkscreen.
    [ecu-board.kicad_pcb]
2019-10-12 Add lots of silk screen.
    [ecu-board.kicad_pcb]
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2019-10-12 Clean up copper pours.
    [ecu-board.kicad_pcb]
2019-10-12 Generate PDF and SVG files.
    [ecu-board.kicad_pcb]
2019-10-12 Change to a larger diode footprint.
    [connectors.sch, ecu-board.kicad_pcb, relays.sch]
2019-10-12 Correct unconnected pad.
    [ecu-board.kicad_pcb]
2019-10-13 Move relays and additional final touches.
    [ecu-board.kicad_pcb, ecu-board.sch]
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2019-10-13 Add step 3D model.
    [ecu-board.step]
